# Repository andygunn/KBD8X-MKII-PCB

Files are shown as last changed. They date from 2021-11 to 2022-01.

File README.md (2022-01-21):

# KBD8X-MKII-PCB
This is the source for the PCB used in the [KBD8X MKII by KBDfans](https://kbdfans.com/collections/kbd8x-mkii/products/coming-soon-kbd8x-mkii-custom-mechanical-keyboard-kit) by [ai03](https://kb.ai03.me). There have been a number of modifications to this PCB:
- Changed the MX-only footprints to MX/Alps-compatible footprints.
- Modified the routing of traces to accomodate the new footprints.
- Changed the ATmega32U4 from the -MU variety to the -AU variety so it could be hand-soldered (due to component shortages)

This PCB should work with the same firmware files as the original PCB, as the MCU and matrix are the same.

Note that this PCB is offered as-is with NO WARRANTY. If you produce it, you may encounter problems.

Please verify the conditions of the [license](https://github.com/ai03-2725/KBD8X-MKII-PCB/blob/master/LICENSE) before using.

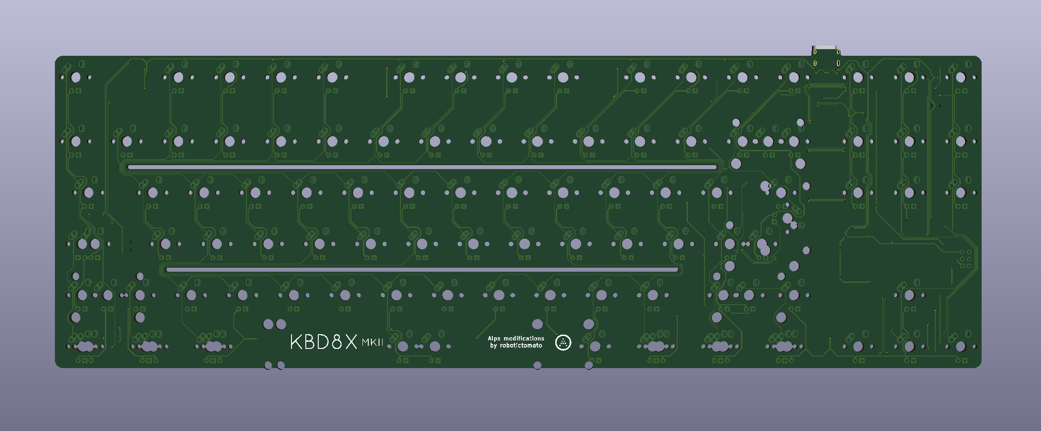
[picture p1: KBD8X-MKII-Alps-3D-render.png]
render


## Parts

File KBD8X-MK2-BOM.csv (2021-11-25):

Comment | Designator | Footprint | LCSC
1uF | C2 | locallib:C_0603 | C15849
22pF | C3,C4 | locallib:C_0603 | C1653
10uF | C5 | locallib:C_0603 | C19702
0.1uF | CRGB1,CRGB2,CRGB3,CRGB4,CRGB5,C6,CRGB6,C7,CRGB7,C8,CRGB8,CRGB9,CRGB10,CRGB11,CRGB12,CRGB13,CRGB14,CRGB15,CRGB16,CRGB17,CRGB18 | locallib:C_0603 | C2167300
SOD-323 | D1,D2,D3,D4,D5,D6,D7,D8,D9,D10,D11,D12,D13,D14,D17,D18,D19,D20,D21,D22,D23,D24,D25,D26,D27,D28,D29,D30,D31,D35,D36,D37,D38,D39,D40,D41,D42,D43,D44,D45,D46,D47,D48,D52,D53,D54,D55,D56,D57,D58,D59,D60,D61,D62,D63,D65,D66,D67,D68,D69,D70,D71,D72,D73,D74,D75,D76,D77,D78,D81,D82,D84,D85,D86,D87,D90,D91,D92,D93,D94,D95,D96,D97,D99,D100,D101,D108,D111,D112,D113 | locallib:D_SOD-123 | C81598
500mA | F1 | Fuse_Holders_and_Fuses:Fuse_SMD1206_Wave | C151162
DSS60601MZ4-13 | Q1 | TO_SOT_Packages_SMD:SOT-223-3_TabPin2 | C150451
22 | RC1,RC2 | locallib:R_0603 | C23345
10k | RC3 | locallib:R_0603 | C25804
1k | R1,R2,R3,RC4,R4,R5,R6,R7,R8,R9,R10,R11,R12,R13,R14,R16,R17,R18,R19,R20,R21,R22,R23,R24,R25,R26,R27,R28,R29,R30,R31,R32,R33,R35,R36,R37,R38,R39,R40,R41,R42,R43,R44,R45,R46,R47,R48,R52,R53,R54,R55,R56,R57,R58,R59,R60,R61,R62,R63,R65,R66,R67,R68,R69,R70,R71,R72,R73,R74,R75,R76,R77,R78,R81,R82,R84,R85,R86,R87,R90,R91,R95,R96,R97,R99,R100,R101,R108,R111,R112,R113 | locallib:R_0603 | C21190
1.5k | RC5 | locallib:R_0603 | C22843
5k1 | RC6,RC7 | locallib:R_0603 | C23186
WS2812B | RGB1,RGB2,RGB3,RGB4,RGB5,RGB6,RGB7,RGB8,RGB9,RGB10,RGB11,RGB12,RGB13,RGB14,RGB15,RGB16,RGB17,RGB18 | locallib:LED_WS2812B-PLCC4 | C2761795
SW_Push | SW1 | random-keyboard-parts:SKQG-1155865 | C116647
SW_SPDT | SW2,SW3 | Buttons_Switches_SMD:SW_SPDT_PCM12 | C221841
ATmega32U4-MU | U1 | locallib:QFN-44-1EP_7x7mm_Pitch0.5mm | C112161
PRTR5V0U2X | U2 | locallib:SOT143B | C12333
HRO-TYPE-C-31-M-12 | USB1 | Type-C:HRO-TYPE-C-31-M-12-Assembly | C165948
16MHz | Y1 | locallib:Crystal_SMD_3225-4pin_3.2x2.5mm | C255906

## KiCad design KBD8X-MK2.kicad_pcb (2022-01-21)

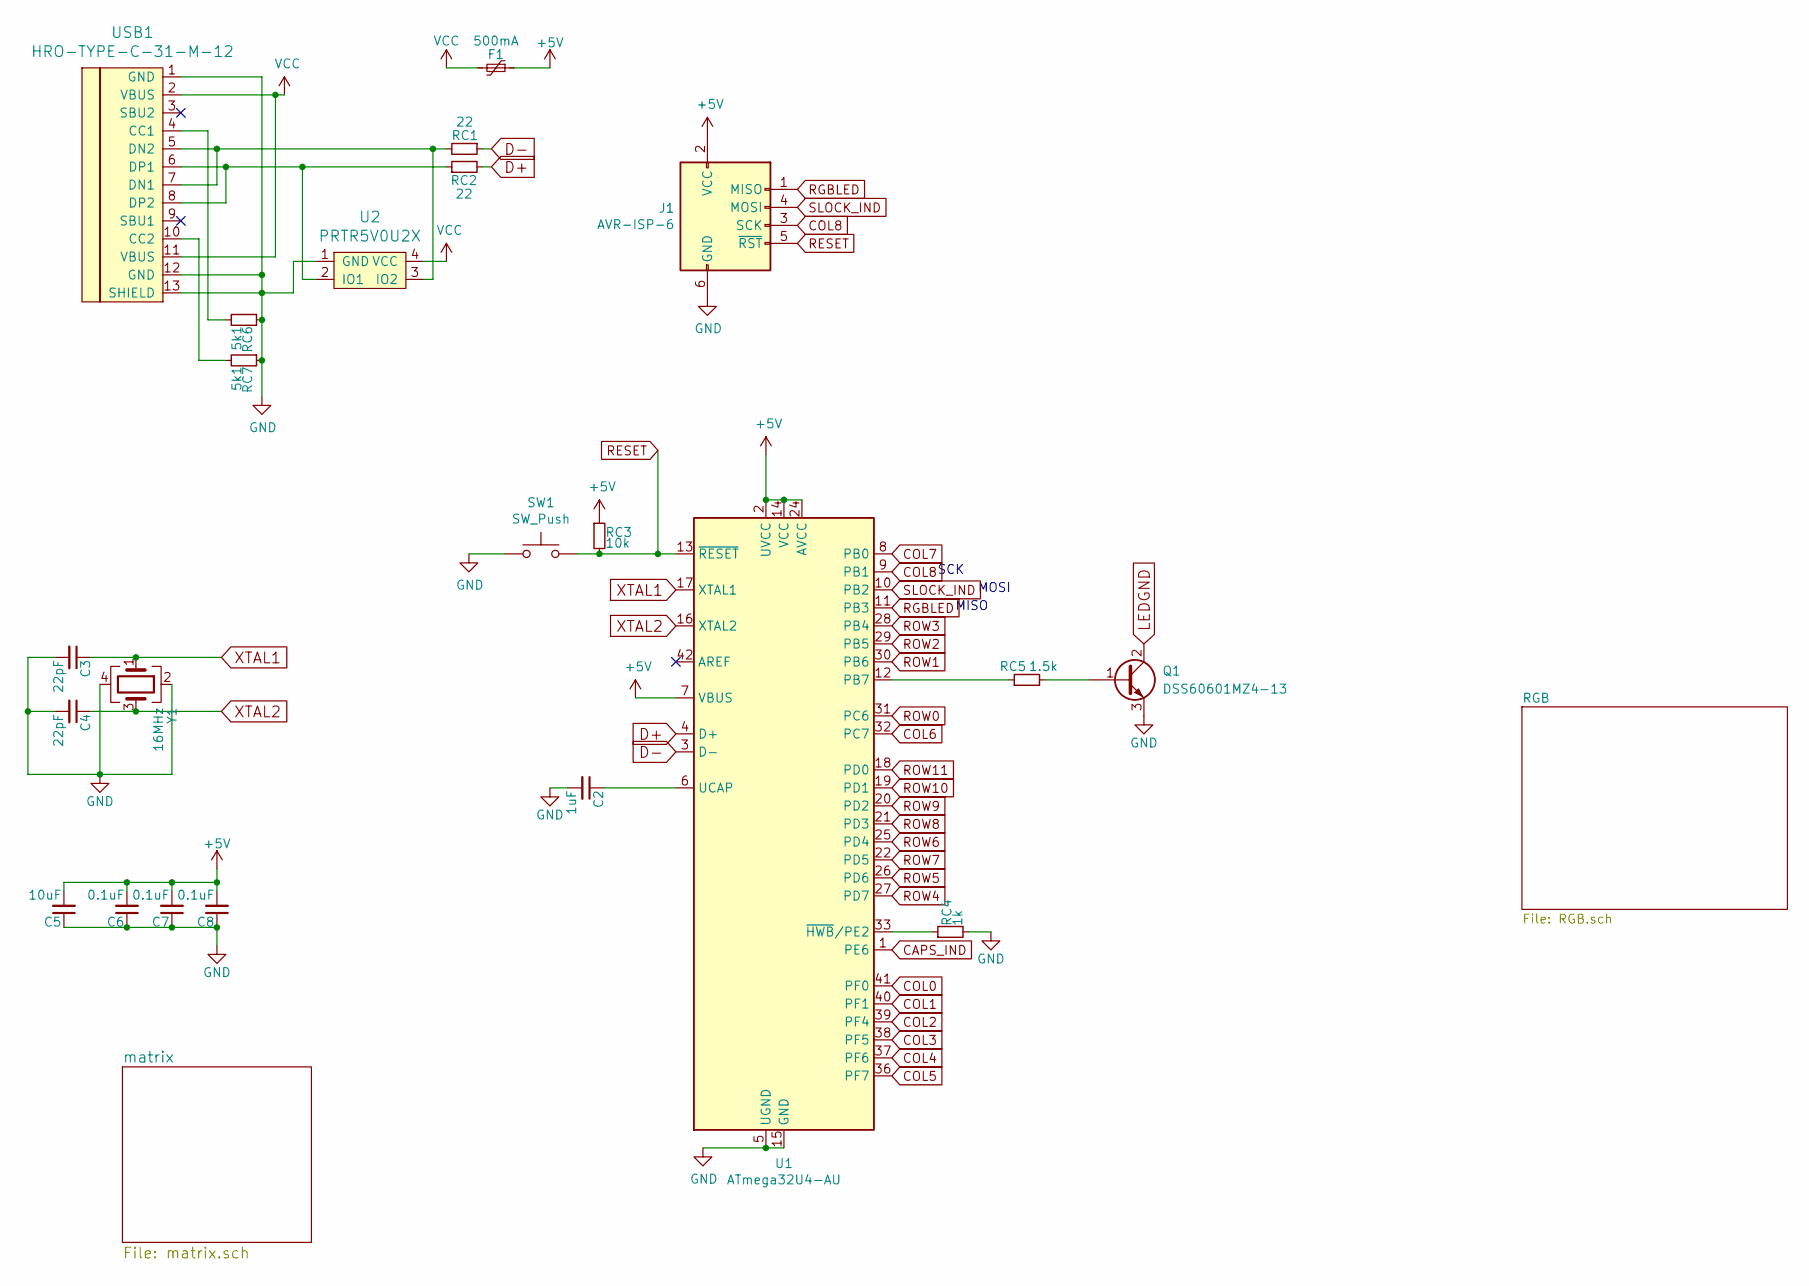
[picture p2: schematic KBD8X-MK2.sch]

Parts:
C2: 1uF; C_0603
C3, C4: 22pF; C_0603
C5: 10uF; C_0603
C6, C7, C8: 0.1uF; C_0603
F1: 500mA; Fuse_SMD1206_Wave
J1: AVR-ISP-6; Reset_Pretty-Mask
Q1: DSS60601MZ4-13; SOT-223-3_TabPin2
RC1, RC2: 22; R_0603
RC3: 10k; R_0603
RC4: 1k; R_0603
RC5: 1.5k; R_0603
RC6, RC7: 5k1; R_0603
SW1: SW_Push; SKQG-1155865
U1: ATmega32U4-AU; TQFP-44_10x10mm_P0.8mm
U2: PRTR5V0U2X; SOT143B
USB1: HRO-TYPE-C-31-M-12; HRO-TYPE-C-31-M-12-Assembly
Y1: 16MHz; Crystal_SMD_3225-4pin_3.2x2.5mm

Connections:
+5V: C5.2, C6.2, C7.2, C8.2, F1.1, J1.2 (VCC), RC3.1, U1.2 (UVCC), U1.7 (VBUS), U1.14 (VCC), U1.24 (AVCC), U1.34 (VCC), U1.44 (AVCC); also elsewhere on the board
CAPS_IND: U1.1 (PE6); also elsewhere on the board
COL0: U1.41 (PF0); also elsewhere on the board
COL1: U1.40 (PF1); also elsewhere on the board
COL2: U1.39 (PF4); also elsewhere on the board
COL3: U1.38 (PF5); also elsewhere on the board
COL4: U1.37 (PF6); also elsewhere on the board
COL5: U1.36 (PF7); also elsewhere on the board
COL6: U1.32 (PC7); also elsewhere on the board
COL7: U1.8 (PB0); also elsewhere on the board
COL8: J1.3 (SCK), U1.9 (PB1); also elsewhere on the board
D+: RC2.2, U1.4 (D+)
D-: RC1.1, U1.3 (D-)
GND: C2.2, C3.2, C4.2, C5.1, C6.1, C7.1, C8.1, J1.6 (GND), Q1.3 (E), RC4.2, RC6.1, RC7.1, SW1.1, U1.5 (UGND), U1.15 (GND), U1.23 (GND), U1.35 (GND), U1.43 (GND), U1.45 (GND), U2.1 (GND), USB1.1 (GND), USB1.12 (GND), USB1.13 (SHIELD), Y1.2, Y1.4; also elsewhere on the board
LEDGND: Q1.2 (C); also elsewhere on the board
unnamed: C2.1, U1.6 (UCAP)
unnamed: Q1.1 (B), RC5.2
unnamed: RC1.2, U2.3 (IO2), USB1.5 (DN2), USB1.7 (DN1)
unnamed: RC2.1, U2.2 (IO1), USB1.6 (DP1), USB1.8 (DP2)
unnamed: RC4.1, U1.33 (~HWB~/PE2)
unnamed: RC5.1, U1.12 (PB7)
unnamed: RC6.2, USB1.4 (CC1)
unnamed: RC7.2, USB1.10 (CC2)
RESET: J1.5 (~RST), RC3.2, SW1.2, U1.13 (~RESET)
RGBLED: J1.1 (MISO), U1.11 (PB3); also elsewhere on the board
ROW0: U1.31 (PC6); also elsewhere on the board
ROW1: U1.30 (PB6); also elsewhere on the board
ROW2: U1.29 (PB5); also elsewhere on the board
ROW3: U1.28 (PB4); also elsewhere on the board
ROW4: U1.27 (PD7); also elsewhere on the board
ROW5: U1.26 (PD6); also elsewhere on the board
ROW6: U1.25 (PD4); also elsewhere on the board
ROW7: U1.22 (PD5); also elsewhere on the board
ROW8: U1.21 (PD3); also elsewhere on the board
ROW9: U1.20 (PD2); also elsewhere on the board
ROW10: U1.19 (PD1); also elsewhere on the board
ROW11: U1.18 (PD0); also elsewhere on the board
SLOCK_IND: J1.4 (MOSI), U1.10 (PB2); also elsewhere on the board
VCC: F1.2, U2.4 (VCC), USB1.2 (VBUS), USB1.11 (VBUS)
XTAL1: C3.1, U1.17 (XTAL1), Y1.1
XTAL2: C4.1, U1.16 (XTAL2), Y1.3

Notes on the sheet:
MOSI
MISO
SCK

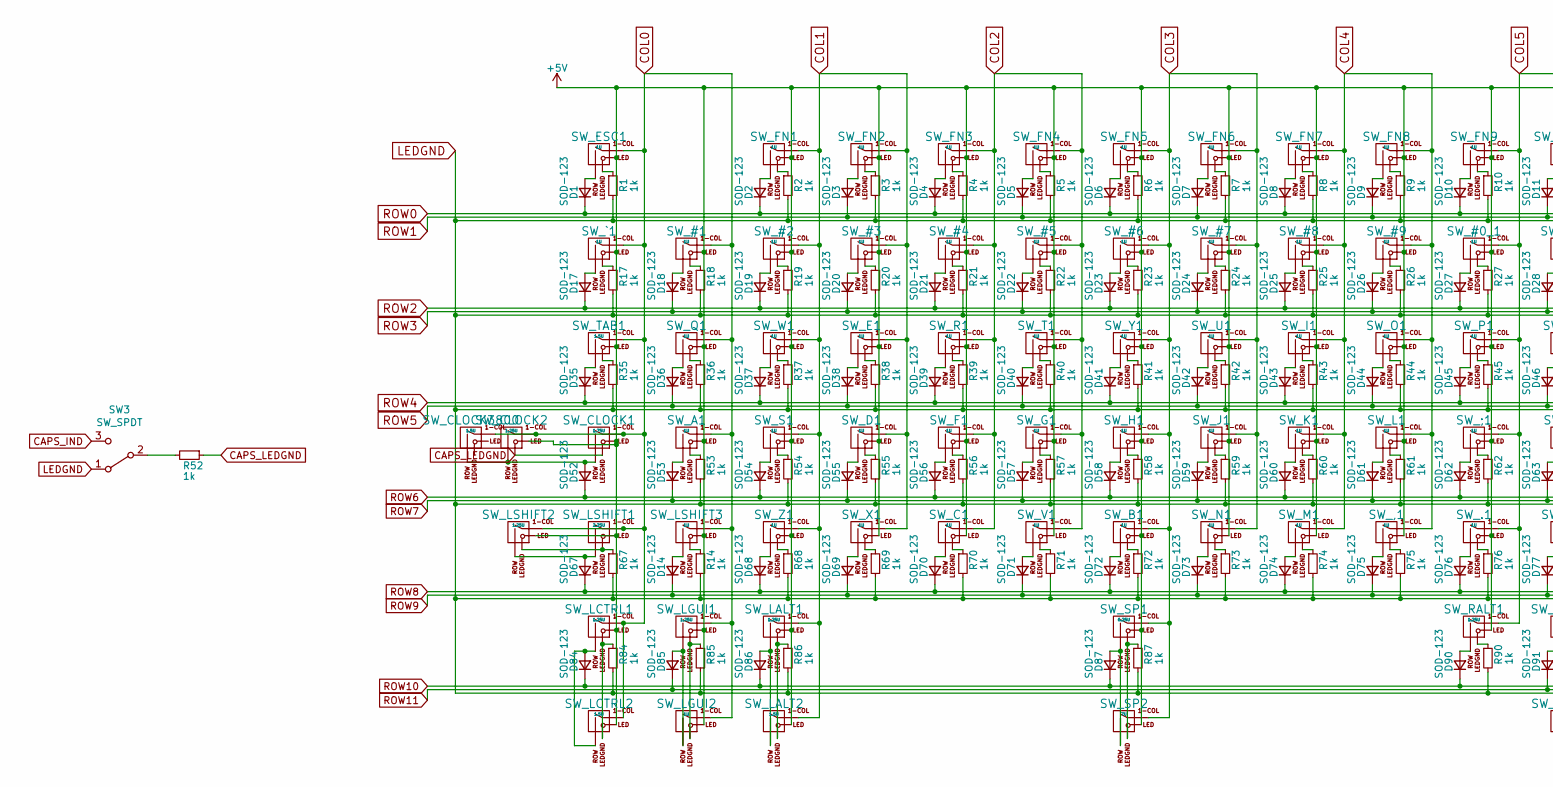
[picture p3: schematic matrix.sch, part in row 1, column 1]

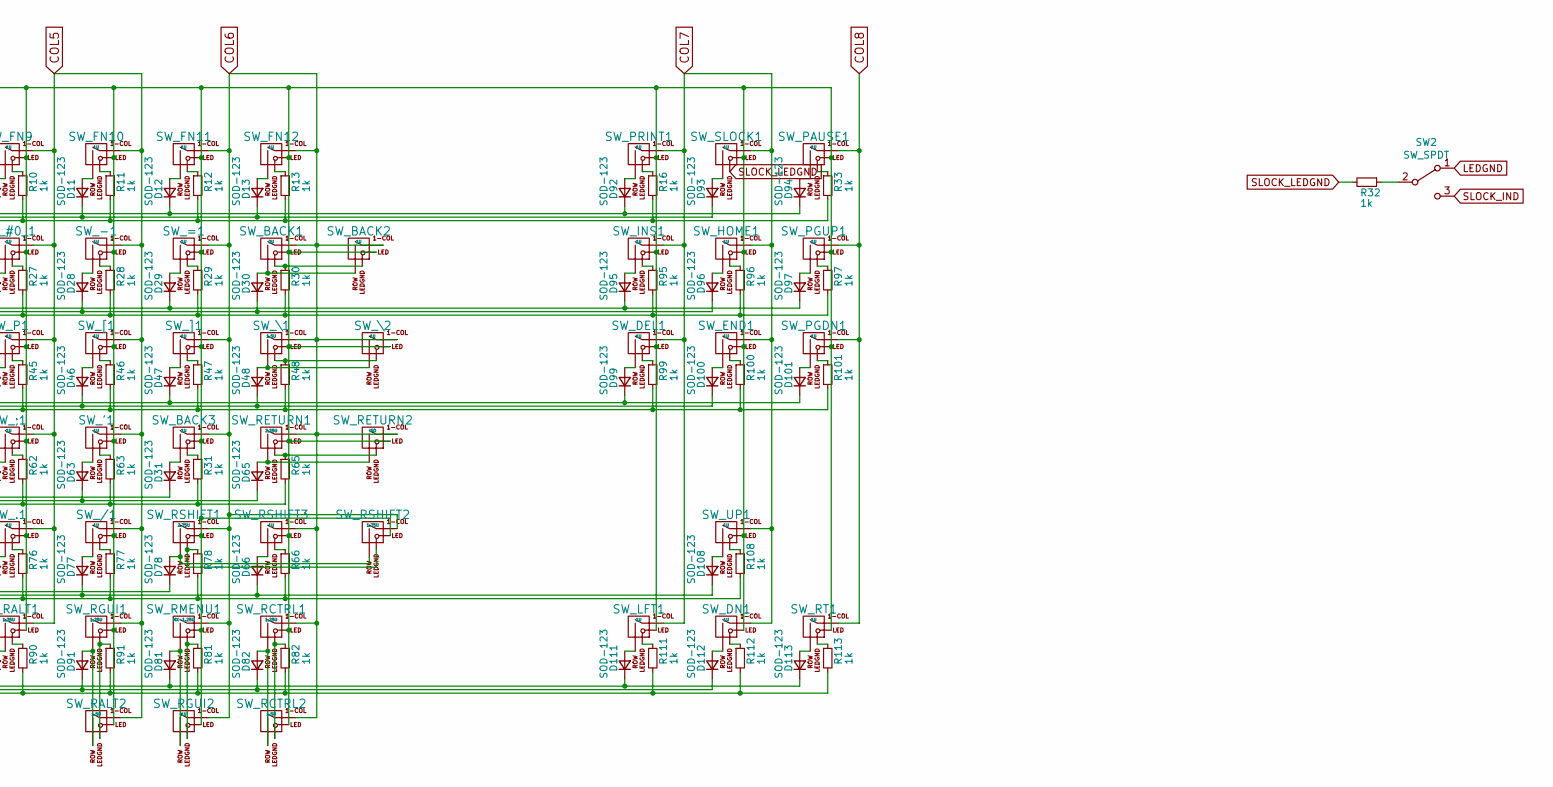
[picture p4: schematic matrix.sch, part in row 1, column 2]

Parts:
D1, D2, D3, D4, D5, D6, D7, D8, D9, D10, D11, D12, D13, D14, D17, D18, D19, D20, D21, D22, D23, D24, D25, D26, D27, D28, D29, D30, D31, D35, D36, D37, D38, D39, D40, D41, D42, D43, D44, D45, D46, D47, D48, D52, D53, D54, D55, D56, D57, D58, D59, D60, D61, D62, D63, D65, D66, D67, D68, D69, D70, D71, D72, D73, D74, D75, D76, D77, D78, D81, D82, D84, D85, D86, D87, D90, D91, D92, D93, D94, D95, D96, D97, D99, D100, D101, D108, D111, D112, D113: SOD-123; D_SOD-123
R1, R2, R3, R4, R5, R6, R7, R8, R9, R10, R11, R12, R13, R14, R16, R17, R18, R19, R20, R21, R22, R23, R24, R25, R26, R27, R28, R29, R30, R31, R32, R33, R35, R36, R37, R38, R39, R40, R41, R42, R43, R44, R45, R46, R47, R48, R52, R53, R54, R55, R56, R57, R58, R59, R60, R61, R62, R63, R65, R66, R67, R68, R69, R70, R71, R72, R73, R74, R75, R76, R77, R78, R81, R82, R84, R85, R86, R87, R90, R91, R95, R96, R97, R99, R100, R101, R108, R111, R112, R113: 1k; R_0603
SW2, SW3: SW_SPDT; SW_SPDT_PCM12
SW_#0_1, SW_#1, SW_#2, SW_#3, SW_#4, SW_#5, SW_#6, SW_#7, SW_#8, SW_#9: 1U; MX-1U
SW_'1: 1U; MX-1U
SW_,1: 1U; MX-1U
SW_-1: 1U; MX-1U
SW_.1: 1U; MX-1U
SW_/1: 1U; MX-1U
SW_;1: 1U; MX-1U
SW_=1: 1U; MX-1U
SW_A1: 1U; MX-1U
SW_B1: 1U; MX-1U
SW_BACK1: 2U; MX-2U
SW_BACK2, SW_BACK3: 1U; MX-1U
SW_C1: 1U; MX-1U
SW_CLOCK1: 1.75U; MX-1.75U
SW_CLOCK2: 1.25U; MX-1.25U-FLIPPED
SW_CLOCK3800: 1.5U; ALPS-1.5U
SW_D1: 1U; MX-1U
SW_DEL1: 1U; MX-1U
SW_DN1: 1U; MX-1U
SW_E1: 1U; MX-1U
SW_END1: 1U; MX-1U
SW_ESC1: 1U; MX-1U
SW_F1: 1U; MX-1U
SW_FN1, SW_FN2, SW_FN3, SW_FN4, SW_FN5, SW_FN6, SW_FN7, SW_FN8, SW_FN9, SW_FN10, SW_FN11, SW_FN12: 1U; MX-1U
SW_G1: 1U; MX-1U
SW_H1: 1U; MX-1U
SW_HOME1: 1U; MX-1U
SW_I1: 1U; MX-1U
SW_INS1: 1U; MX-1U
SW_J1: 1U; MX-1U
SW_K1: 1U; MX-1U
SW_L1: 1U; MX-1U
SW_LALT1: 1.25U; MX-1.25U
SW_LALT2: 1.5U; MX-1.5U-FLIPPED
SW_LCTRL1: 1.25U; MX-1.25U
SW_LCTRL2: 1.5U; MX-1.5U-FLIPPED
SW_LFT1: 1U; MX-1U
SW_LGUI1: 1.25U; MX-1.25U
SW_LGUI2: 1U; MX-1U-FLIPPED
SW_LSHIFT1: 2.25U; MX-2.25U
SW_LSHIFT2: 1.25U; MX-1.25U
SW_LSHIFT3: 1U; MX-1U
SW_M1: 1U; MX-1U
SW_N1: 1U; MX-1U
SW_O1: 1U; MX-1U
SW_P1: 1U; MX-1U
SW_PAUSE1: 1U; MX-1U
SW_PGDN1: 1U; MX-1U
SW_PGUP1: 1U; MX-1U
SW_PRINT1: 1U; MX-1U
SW_Q1: 1U; MX-1U
SW_R1: 1U; MX-1U
SW_RALT1: 1.25U; MX-1.25U
SW_RALT2: 1.5U; MX-1.5U
SW_RCTRL1: 1.25U; MX-1.25U-FLIPPED
SW_RCTRL2: 1.5U; MX-1.5U
SW_RETURN1: 2.25U; MX-2.25U
SW_RETURN2: ISO; MX-ISO-ReversedStabilizers
SW_RGUI1: 1.25U; MX-1.25U-FLIPPED
SW_RGUI2: 1U; MX-1U
SW_RMENU1: MX-1.25U; MX-1.25U-FLIPPED
SW_RSHIFT1: 2.75U; MX-2.75U
SW_RSHIFT2: 1.75U; MX-1.75U
SW_RSHIFT3: 1U; MX-1U
SW_RT1: 1U; MX-1U
SW_S1: 1U; MX-1U
SW_SLOCK1: 1U; MX-1U
SW_SP1: 6.25U; MX-6.25U-ReversedStabilizers
SW_SP2: 7U; MX-7U-ReversedStabilizers
SW_T1: 1U; MX-1U
SW_TAB1: 1.5U; MX-1.5U
SW_U1: 1U; MX-1U
SW_UP1: 1U; MX-1U
SW_V1: 1U; MX-1U
SW_W1: 1U; MX-1U
SW_X1: 1U; MX-1U
SW_Y1: 1U; MX-1U
SW_Z1: 1U; MX-1U
SW_[1: 1U; MX-1U
SW_\1: 1.5U; MX-1.5U
SW_\2: 1U; MX-1U
SW_]1: 1U; MX-1U
SW_`1: 1U; MX-1U

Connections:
+5V: SW_#0_1.3 (LED), SW_#1.3 (LED), SW_#2.3 (LED), SW_#3.3 (LED), SW_#4.3 (LED), SW_#5.3 (LED), SW_#6.3 (LED), SW_#7.3 (LED), SW_#8.3 (LED), SW_#9.3 (LED), SW_'1.3 (LED), SW_,1.3 (LED), SW_-1.3 (LED), SW_.1.3 (LED), SW_/1.3 (LED), SW_;1.3 (LED), SW_=1.3 (LED), SW_A1.3 (LED), SW_B1.3 (LED), SW_BACK1.3 (LED), SW_BACK2.3 (LED), SW_BACK3.3 (LED), SW_C1.3 (LED), SW_CLOCK1.3 (LED), SW_CLOCK2.3 (LED), SW_D1.3 (LED), SW_DEL1.3 (LED), SW_DN1.3 (LED), SW_E1.3 (LED), SW_END1.3 (LED), SW_ESC1.3 (LED), SW_F1.3 (LED), SW_FN1.3 (LED), SW_FN2.3 (LED), SW_FN3.3 (LED), SW_FN4.3 (LED), SW_FN5.3 (LED), SW_FN6.3 (LED), SW_FN7.3 (LED), SW_FN8.3 (LED), SW_FN9.3 (LED), SW_FN10.3 (LED), SW_FN11.3 (LED), SW_FN12.3 (LED), SW_G1.3 (LED), SW_H1.3 (LED), SW_HOME1.3 (LED), SW_I1.3 (LED), SW_INS1.3 (LED), SW_J1.3 (LED), SW_K1.3 (LED), SW_L1.3 (LED), SW_LALT1.3 (LED), SW_LALT2.3 (LED), SW_LCTRL1.3 (LED), SW_LCTRL2.3 (LED), SW_LFT1.3 (LED), SW_LGUI1.3 (LED), SW_LGUI2.3 (LED), SW_LSHIFT1.3 (LED), SW_LSHIFT2.3 (LED), SW_LSHIFT3.3 (LED), SW_M1.3 (LED), SW_N1.3 (LED), SW_O1.3 (LED), SW_P1.3 (LED), SW_PAUSE1.3 (LED), SW_PGDN1.3 (LED), SW_PGUP1.3 (LED), SW_PRINT1.3 (LED), SW_Q1.3 (LED), SW_R1.3 (LED), SW_RALT1.3 (LED), SW_RALT2.3 (LED), SW_RCTRL1.3 (LED), SW_RCTRL2.3 (LED), SW_RETURN1.3 (LED), SW_RETURN2.3 (LED), SW_RGUI1.3 (LED), SW_RGUI2.3 (LED), SW_RMENU1.3 (LED), SW_RSHIFT1.3 (LED), SW_RSHIFT2.3 (LED), SW_RSHIFT3.3 (LED), SW_RT1.3 (LED), SW_S1.3 (LED), SW_SLOCK1.3 (LED), SW_SP1.3 (LED), SW_SP2.3 (LED), SW_T1.3 (LED), SW_TAB1.3 (LED), SW_U1.3 (LED), SW_UP1.3 (LED), SW_V1.3 (LED), SW_W1.3 (LED), SW_X1.3 (LED), SW_Y1.3 (LED), SW_Z1.3 (LED), SW_[1.3 (LED), SW_\1.3 (LED), SW_\2.3 (LED), SW_]1.3 (LED), SW_`1.3 (LED); also elsewhere on the board
CAPS_IND: SW3.3 (C); also elsewhere on the board
CAPS_LEDGND: R52.1, SW_CLOCK1.4 (LEDGND), SW_CLOCK2.4 (LEDGND)
COL0: SW_#1.1 (COL), SW_A1.1 (COL), SW_CLOCK1.1 (COL), SW_CLOCK2.1 (COL), SW_CLOCK3800.1 (COL), SW_ESC1.1 (COL), SW_LCTRL1.1 (COL), SW_LCTRL2.1 (COL), SW_LGUI1.1 (COL), SW_LGUI2.1 (COL), SW_LSHIFT1.1 (COL), SW_LSHIFT2.1 (COL), SW_LSHIFT3.1 (COL), SW_Q1.1 (COL), SW_TAB1.1 (COL), SW_`1.1 (COL); also elsewhere on the board
COL1: SW_#2.1 (COL), SW_#3.1 (COL), SW_D1.1 (COL), SW_E1.1 (COL), SW_FN1.1 (COL), SW_FN2.1 (COL), SW_LALT1.1 (COL), SW_LALT2.1 (COL), SW_S1.1 (COL), SW_W1.1 (COL), SW_X1.1 (COL), SW_Z1.1 (COL); also elsewhere on the board
COL2: SW_#4.1 (COL), SW_#5.1 (COL), SW_C1.1 (COL), SW_F1.1 (COL), SW_FN3.1 (COL), SW_FN4.1 (COL), SW_G1.1 (COL), SW_R1.1 (COL), SW_T1.1 (COL), SW_V1.1 (COL); also elsewhere on the board
COL3: SW_#6.1 (COL), SW_#7.1 (COL), SW_B1.1 (COL), SW_FN5.1 (COL), SW_FN6.1 (COL), SW_H1.1 (COL), SW_J1.1 (COL), SW_N1.1 (COL), SW_SP1.1 (COL), SW_SP2.1 (COL), SW_U1.1 (COL), SW_Y1.1 (COL); also elsewhere on the board
COL4: SW_#8.1 (COL), SW_#9.1 (COL), SW_,1.1 (COL), SW_FN7.1 (COL), SW_FN8.1 (COL), SW_I1.1 (COL), SW_K1.1 (COL), SW_L1.1 (COL), SW_M1.1 (COL), SW_O1.1 (COL); also elsewhere on the board
COL5: SW_#0_1.1 (COL), SW_'1.1 (COL), SW_-1.1 (COL), SW_.1.1 (COL), SW_/1.1 (COL), SW_;1.1 (COL), SW_FN9.1 (COL), SW_FN10.1 (COL), SW_P1.1 (COL), SW_RALT1.1 (COL), SW_RALT2.1 (COL), SW_RGUI1.1 (COL), SW_[1.1 (COL); also elsewhere on the board
COL6: SW_=1.1 (COL), SW_BACK1.1 (COL), SW_BACK2.1 (COL), SW_BACK3.1 (COL), SW_FN11.1 (COL), SW_FN12.1 (COL), SW_RCTRL1.1 (COL), SW_RCTRL2.1 (COL), SW_RETURN1.1 (COL), SW_RETURN2.1 (COL), SW_RGUI2.1 (COL), SW_RMENU1.1 (COL), SW_RSHIFT1.1 (COL), SW_RSHIFT2.1 (COL), SW_RSHIFT3.1 (COL), SW_\1.1 (COL), SW_\2.1 (COL), SW_]1.1 (COL); also elsewhere on the board
COL7: SW_DEL1.1 (COL), SW_DN1.1 (COL), SW_END1.1 (COL), SW_HOME1.1 (COL), SW_INS1.1 (COL), SW_LFT1.1 (COL), SW_PRINT1.1 (COL), SW_SLOCK1.1 (COL), SW_UP1.1 (COL); also elsewhere on the board
COL8: SW_PAUSE1.1 (COL), SW_PGDN1.1 (COL), SW_PGUP1.1 (COL), SW_RT1.1 (COL); also elsewhere on the board
LEDGND: R1.2, R2.2, R3.2, R4.2, R5.2, R6.2, R7.2, R8.2, R9.2, R10.2, R11.2, R12.2, R13.2, R14.2, R16.2, R17.2, R18.2, R19.2, R20.2, R21.2, R22.2, R23.2, R24.2, R25.2, R26.2, R27.2, R28.2, R29.2, R30.2, R31.2, R33.2, R35.2, R36.2, R37.2, R38.2, R39.2, R40.2, R41.2, R42.2, R43.2, R44.2, R45.2, R46.2, R47.2, R48.2, R53.2, R54.2, R55.2, R56.2, R57.2, R58.2, R59.2, R60.2, R61.2, R62.2, R63.2, R65.2, R66.2, R67.2, R68.2, R69.2, R70.2, R71.2, R72.2, R73.2, R74.2, R75.2, R76.2, R77.2, R78.2, R81.2, R82.2, R84.2, R85.2, R86.2, R87.2, R90.2, R91.2, R95.2, R96.2, R97.2, R99.2, R100.2, R101.2, R108.2, R111.2, R112.2, R113.2, SW2.1 (A), SW3.1 (A); also elsewhere on the board
unnamed: D1.2 (A), SW_ESC1.2 (ROW)
unnamed: D2.2 (A), SW_FN1.2 (ROW)
unnamed: D3.2 (A), SW_FN2.2 (ROW)
unnamed: D4.2 (A), SW_FN3.2 (ROW)
unnamed: D5.2 (A), SW_FN4.2 (ROW)
unnamed: D6.2 (A), SW_FN5.2 (ROW)
unnamed: D7.2 (A), SW_FN6.2 (ROW)
unnamed: D8.2 (A), SW_FN7.2 (ROW)
unnamed: D9.2 (A), SW_FN8.2 (ROW)
unnamed: D10.2 (A), SW_FN9.2 (ROW)
unnamed: D11.2 (A), SW_FN10.2 (ROW)
unnamed: D12.2 (A), SW_FN11.2 (ROW)
unnamed: D13.2 (A), SW_FN12.2 (ROW)
unnamed: D14.2 (A), SW_LSHIFT3.2 (ROW)
unnamed: D17.2 (A), SW_`1.2 (ROW)
unnamed: D18.2 (A), SW_#1.2 (ROW)
unnamed: D19.2 (A), SW_#2.2 (ROW)
unnamed: D20.2 (A), SW_#3.2 (ROW)
unnamed: D21.2 (A), SW_#4.2 (ROW)
unnamed: D22.2 (A), SW_#5.2 (ROW)
unnamed: D23.2 (A), SW_#6.2 (ROW)
unnamed: D24.2 (A), SW_#7.2 (ROW)
unnamed: D25.2 (A), SW_#8.2 (ROW)
unnamed: D26.2 (A), SW_#9.2 (ROW)
unnamed: D27.2 (A), SW_#0_1.2 (ROW)
unnamed: D28.2 (A), SW_-1.2 (ROW)
unnamed: D29.2 (A), SW_=1.2 (ROW)
unnamed: D30.2 (A), SW_BACK1.2 (ROW), SW_BACK2.2 (ROW)
unnamed: D31.2 (A), SW_BACK3.2 (ROW)
unnamed: D35.2 (A), SW_TAB1.2 (ROW)
unnamed: D36.2 (A), SW_Q1.2 (ROW)
unnamed: D37.2 (A), SW_W1.2 (ROW)
unnamed: D38.2 (A), SW_E1.2 (ROW)
unnamed: D39.2 (A), SW_R1.2 (ROW)
unnamed: D40.2 (A), SW_T1.2 (ROW)
unnamed: D41.2 (A), SW_Y1.2 (ROW)
unnamed: D42.2 (A), SW_U1.2 (ROW)
unnamed: D43.2 (A), SW_I1.2 (ROW)
unnamed: D44.2 (A), SW_O1.2 (ROW)
unnamed: D45.2 (A), SW_P1.2 (ROW)
unnamed: D46.2 (A), SW_[1.2 (ROW)
unnamed: D47.2 (A), SW_]1.2 (ROW)
unnamed: D48.2 (A), SW_\1.2 (ROW), SW_\2.2 (ROW)
unnamed: D52.2 (A), SW_CLOCK1.2 (ROW), SW_CLOCK2.2 (ROW), SW_CLOCK3800.2 (ROW)
unnamed: D53.2 (A), SW_A1.2 (ROW)
unnamed: D54.2 (A), SW_S1.2 (ROW)
unnamed: D55.2 (A), SW_D1.2 (ROW)
unnamed: D56.2 (A), SW_F1.2 (ROW)
unnamed: D57.2 (A), SW_G1.2 (ROW)
unnamed: D58.2 (A), SW_H1.2 (ROW)
unnamed: D59.2 (A), SW_J1.2 (ROW)
unnamed: D60.2 (A), SW_K1.2 (ROW)
unnamed: D61.2 (A), SW_L1.2 (ROW)
unnamed: D62.2 (A), SW_;1.2 (ROW)
unnamed: D63.2 (A), SW_'1.2 (ROW)
unnamed: D65.2 (A), SW_RETURN1.2 (ROW), SW_RETURN2.2 (ROW)
unnamed: D66.2 (A), SW_RSHIFT3.2 (ROW)
unnamed: D67.2 (A), SW_LSHIFT1.2 (ROW), SW_LSHIFT2.2 (ROW)
unnamed: D68.2 (A), SW_Z1.2 (ROW)
unnamed: D69.2 (A), SW_X1.2 (ROW)
unnamed: D70.2 (A), SW_C1.2 (ROW)
unnamed: D71.2 (A), SW_V1.2 (ROW)
unnamed: D72.2 (A), SW_B1.2 (ROW)
unnamed: D73.2 (A), SW_N1.2 (ROW)
unnamed: D74.2 (A), SW_M1.2 (ROW)
unnamed: D75.2 (A), SW_,1.2 (ROW)
unnamed: D76.2 (A), SW_.1.2 (ROW)
unnamed: D77.2 (A), SW_/1.2 (ROW)
unnamed: D78.2 (A), SW_RSHIFT1.2 (ROW), SW_RSHIFT2.2 (ROW)
unnamed: D81.2 (A), SW_RGUI2.2 (ROW), SW_RMENU1.2 (ROW)
unnamed: D82.2 (A), SW_RCTRL1.2 (ROW), SW_RCTRL2.2 (ROW)
unnamed: D84.2 (A), SW_LCTRL1.2 (ROW), SW_LCTRL2.2 (ROW)
unnamed: D85.2 (A), SW_LGUI1.2 (ROW), SW_LGUI2.2 (ROW)
unnamed: D86.2 (A), SW_LALT1.2 (ROW), SW_LALT2.2 (ROW)
unnamed: D87.2 (A), SW_SP1.2 (ROW), SW_SP2.2 (ROW)
unnamed: D90.2 (A), SW_RALT1.2 (ROW)
unnamed: D91.2 (A), SW_RALT2.2 (ROW), SW_RGUI1.2 (ROW)
unnamed: D92.2 (A), SW_PRINT1.2 (ROW)
unnamed: D93.2 (A), SW_SLOCK1.2 (ROW)
unnamed: D94.2 (A), SW_PAUSE1.2 (ROW)
unnamed: D95.2 (A), SW_INS1.2 (ROW)
unnamed: D96.2 (A), SW_HOME1.2 (ROW)
unnamed: D97.2 (A), SW_PGUP1.2 (ROW)
unnamed: D99.2 (A), SW_DEL1.2 (ROW)
unnamed: D100.2 (A), SW_END1.2 (ROW)
unnamed: D101.2 (A), SW_PGDN1.2 (ROW)
unnamed: D108.2 (A), SW_UP1.2 (ROW)
unnamed: D111.2 (A), SW_LFT1.2 (ROW)
unnamed: D112.2 (A), SW_DN1.2 (ROW)
unnamed: D113.2 (A), SW_RT1.2 (ROW)
unnamed: R1.1, SW_ESC1.4 (LEDGND)
unnamed: R2.1, SW_FN1.4 (LEDGND)
unnamed: R3.1, SW_FN2.4 (LEDGND)
unnamed: R4.1, SW_FN3.4 (LEDGND)
unnamed: R5.1, SW_FN4.4 (LEDGND)
unnamed: R6.1, SW_FN5.4 (LEDGND)
unnamed: R7.1, SW_FN6.4 (LEDGND)
unnamed: R8.1, SW_FN7.4 (LEDGND)
unnamed: R9.1, SW_FN8.4 (LEDGND)
unnamed: R10.1, SW_FN9.4 (LEDGND)
unnamed: R11.1, SW_FN10.4 (LEDGND)
unnamed: R12.1, SW_FN11.4 (LEDGND)
unnamed: R13.1, SW_FN12.4 (LEDGND)
unnamed: R14.1, SW_LSHIFT3.4 (LEDGND)
unnamed: R16.1, SW_PRINT1.4 (LEDGND)
unnamed: R17.1, SW_`1.4 (LEDGND)
unnamed: R18.1, SW_#1.4 (LEDGND)
unnamed: R19.1, SW_#2.4 (LEDGND)
unnamed: R20.1, SW_#3.4 (LEDGND)
unnamed: R21.1, SW_#4.4 (LEDGND)
unnamed: R22.1, SW_#5.4 (LEDGND)
unnamed: R23.1, SW_#6.4 (LEDGND)
unnamed: R24.1, SW_#7.4 (LEDGND)
unnamed: R25.1, SW_#8.4 (LEDGND)
unnamed: R26.1, SW_#9.4 (LEDGND)
unnamed: R27.1, SW_#0_1.4 (LEDGND)
unnamed: R28.1, SW_-1.4 (LEDGND)
unnamed: R29.1, SW_=1.4 (LEDGND)
unnamed: R30.1, SW_BACK1.4 (LEDGND), SW_BACK2.4 (LEDGND)
unnamed: R31.1, SW_BACK3.4 (LEDGND)
unnamed: R32.1, SW2.2 (B)
unnamed: R33.1, SW_PAUSE1.4 (LEDGND)
unnamed: R35.1, SW_TAB1.4 (LEDGND)
unnamed: R36.1, SW_Q1.4 (LEDGND)
unnamed: R37.1, SW_W1.4 (LEDGND)
unnamed: R38.1, SW_E1.4 (LEDGND)
unnamed: R39.1, SW_R1.4 (LEDGND)
unnamed: R40.1, SW_T1.4 (LEDGND)
unnamed: R41.1, SW_Y1.4 (LEDGND)
unnamed: R42.1, SW_U1.4 (LEDGND)
unnamed: R43.1, SW_I1.4 (LEDGND)
unnamed: R44.1, SW_O1.4 (LEDGND)
unnamed: R45.1, SW_P1.4 (LEDGND)
unnamed: R46.1, SW_[1.4 (LEDGND)
unnamed: R47.1, SW_]1.4 (LEDGND)
unnamed: R48.1, SW_\1.4 (LEDGND), SW_\2.4 (LEDGND)
unnamed: R52.2, SW3.2 (B)
unnamed: R53.1, SW_A1.4 (LEDGND)
unnamed: R54.1, SW_S1.4 (LEDGND)
unnamed: R55.1, SW_D1.4 (LEDGND)
unnamed: R56.1, SW_F1.4 (LEDGND)
unnamed: R57.1, SW_G1.4 (LEDGND)
unnamed: R58.1, SW_H1.4 (LEDGND)
unnamed: R59.1, SW_J1.4 (LEDGND)
unnamed: R60.1, SW_K1.4 (LEDGND)
unnamed: R61.1, SW_L1.4 (LEDGND)
unnamed: R62.1, SW_;1.4 (LEDGND)
unnamed: R63.1, SW_'1.4 (LEDGND)
unnamed: R65.1, SW_RETURN1.4 (LEDGND), SW_RETURN2.4 (LEDGND)
unnamed: R66.1, SW_RSHIFT3.4 (LEDGND)
unnamed: R67.1, SW_LSHIFT1.4 (LEDGND), SW_LSHIFT2.4 (LEDGND)
unnamed: R68.1, SW_Z1.4 (LEDGND)
unnamed: R69.1, SW_X1.4 (LEDGND)
unnamed: R70.1, SW_C1.4 (LEDGND)
unnamed: R71.1, SW_V1.4 (LEDGND)
unnamed: R72.1, SW_B1.4 (LEDGND)
unnamed: R73.1, SW_N1.4 (LEDGND)
unnamed: R74.1, SW_M1.4 (LEDGND)
unnamed: R75.1, SW_,1.4 (LEDGND)
unnamed: R76.1, SW_.1.4 (LEDGND)
unnamed: R77.1, SW_/1.4 (LEDGND)
unnamed: R78.1, SW_RSHIFT1.4 (LEDGND), SW_RSHIFT2.4 (LEDGND)
unnamed: R81.1, SW_RGUI2.4 (LEDGND), SW_RMENU1.4 (LEDGND)
unnamed: R82.1, SW_RCTRL1.4 (LEDGND), SW_RCTRL2.4 (LEDGND)
unnamed: R84.1, SW_LCTRL1.4 (LEDGND), SW_LCTRL2.4 (LEDGND)
unnamed: R85.1, SW_LGUI1.4 (LEDGND), SW_LGUI2.4 (LEDGND)
unnamed: R86.1, SW_LALT1.4 (LEDGND), SW_LALT2.4 (LEDGND)
unnamed: R87.1, SW_SP1.4 (LEDGND), SW_SP2.4 (LEDGND)
unnamed: R90.1, SW_RALT1.4 (LEDGND)
unnamed: R91.1, SW_RALT2.4 (LEDGND), SW_RGUI1.4 (LEDGND)
unnamed: R95.1, SW_INS1.4 (LEDGND)
unnamed: R96.1, SW_HOME1.4 (LEDGND)
unnamed: R97.1, SW_PGUP1.4 (LEDGND)
unnamed: R99.1, SW_DEL1.4 (LEDGND)
unnamed: R100.1, SW_END1.4 (LEDGND)
unnamed: R101.1, SW_PGDN1.4 (LEDGND)
unnamed: R108.1, SW_UP1.4 (LEDGND)
unnamed: R111.1, SW_LFT1.4 (LEDGND)
unnamed: R112.1, SW_DN1.4 (LEDGND)
unnamed: R113.1, SW_RT1.4 (LEDGND)
ROW0: D1.1 (K), D2.1 (K), D4.1 (K), D6.1 (K), D8.1 (K), D10.1 (K), D12.1 (K), D92.1 (K), D94.1 (K); also elsewhere on the board
ROW1: D3.1 (K), D5.1 (K), D7.1 (K), D9.1 (K), D11.1 (K), D13.1 (K), D93.1 (K); also elsewhere on the board
ROW2: D17.1 (K), D19.1 (K), D21.1 (K), D23.1 (K), D25.1 (K), D27.1 (K), D29.1 (K), D95.1 (K), D97.1 (K); also elsewhere on the board
ROW3: D18.1 (K), D20.1 (K), D22.1 (K), D24.1 (K), D26.1 (K), D28.1 (K), D30.1 (K), D96.1 (K); also elsewhere on the board
ROW4: D35.1 (K), D37.1 (K), D39.1 (K), D41.1 (K), D43.1 (K), D45.1 (K), D47.1 (K), D99.1 (K), D101.1 (K); also elsewhere on the board
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

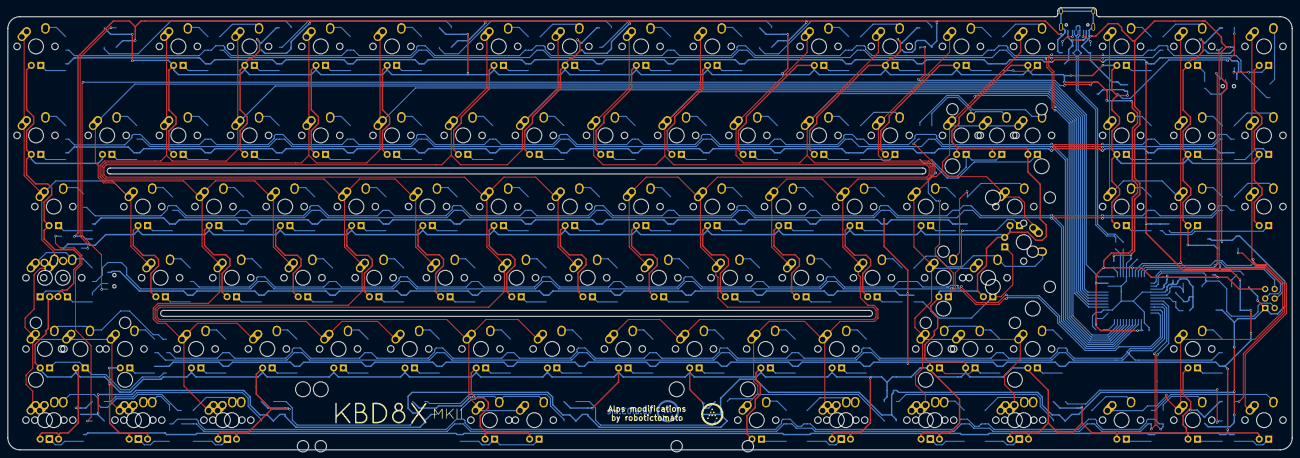
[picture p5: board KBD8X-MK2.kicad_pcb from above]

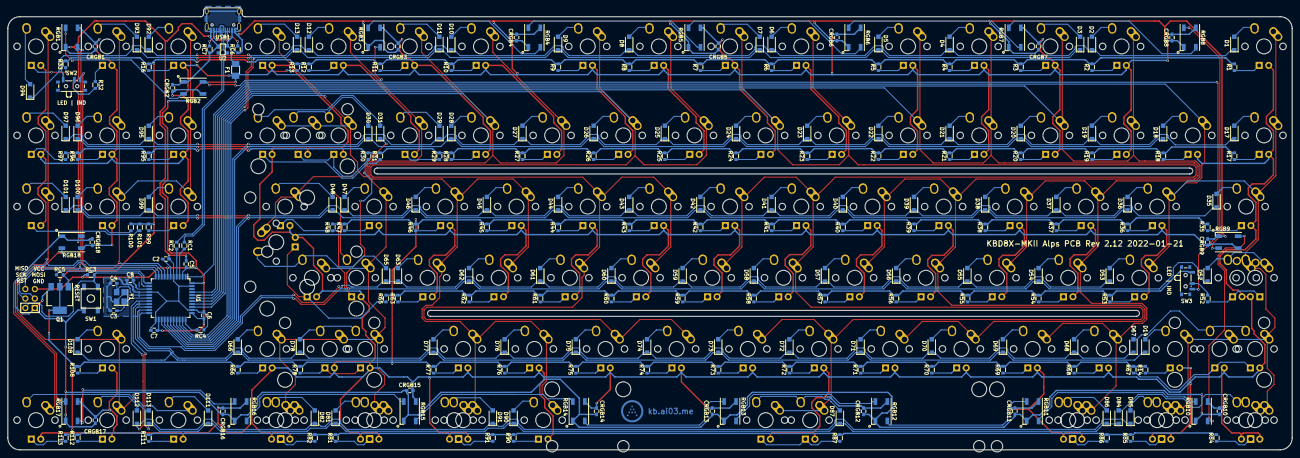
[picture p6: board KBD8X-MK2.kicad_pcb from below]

Board: 2 copper layers, 343.7 x 118.3 mm, 344 parts (240 on the bottom side), 240 nets.

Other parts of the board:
CRGB1, CRGB2, CRGB3, CRGB4, CRGB5, CRGB6, CRGB7, CRGB8, CRGB9, CRGB10, CRGB11, CRGB12, CRGB13, CRGB14, CRGB15, CRGB16, CRGB17, CRGB18: 0.1uF; C_0603
RGB1, RGB2, RGB3, RGB4, RGB5, RGB6, RGB7, RGB8, RGB9, RGB10, RGB11, RGB12, RGB13, RGB14, RGB15, RGB16, RGB17, RGB18: WS2812B; LED_WS2812B-PLCC4

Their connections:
+5V: CRGB1.1, CRGB2.1, CRGB3.1, CRGB4.1, CRGB5.1, CRGB6.1, CRGB7.1, CRGB8.1, CRGB9.1, CRGB10.1, CRGB11.1, CRGB12.1, CRGB13.1, CRGB14.1, CRGB15.1, CRGB16.1, CRGB17.1, CRGB18.1, RGB1.1, RGB2.1, RGB3.1, RGB4.1, RGB5.1, RGB6.1, RGB7.1, RGB8.1, RGB9.1, RGB10.1, RGB11.1, RGB12.1, RGB13.1, RGB14.1, RGB15.1, RGB16.1, RGB17.1, RGB18.1; also elsewhere on the board
GND: CRGB1.2, CRGB2.2, CRGB3.2, CRGB4.2, CRGB5.2, CRGB6.2, CRGB7.2, CRGB8.2, CRGB9.2, CRGB10.2, CRGB11.2, CRGB12.2, CRGB13.2, CRGB14.2, CRGB15.2, CRGB16.2, CRGB17.2, CRGB18.2, RGB1.3, RGB2.3, RGB3.3, RGB4.3, RGB5.3, RGB6.3, RGB7.3, RGB8.3, RGB9.3, RGB10.3, RGB11.3, RGB12.3, RGB13.3, RGB14.3, RGB15.3, RGB16.3, RGB17.3, RGB18.3; also elsewhere on the board
unnamed: RGB1.2, RGB2.4
unnamed: RGB2.2, RGB3.4
unnamed: RGB3.2, RGB4.4
unnamed: RGB4.2, RGB5.4
unnamed: RGB5.2, RGB6.4
unnamed: RGB6.2, RGB7.4
unnamed: RGB7.2, RGB8.4
unnamed: RGB8.2, RGB9.4
unnamed: RGB10.2, RGB11.4
unnamed: RGB9.2, RGB10.4
unnamed: RGB11.2, RGB12.4
unnamed: RGB12.2, RGB13.4
unnamed: RGB13.2, RGB14.4
unnamed: RGB14.2, RGB15.4
unnamed: RGB15.2, RGB16.4
unnamed: RGB16.2, RGB17.4
unnamed: RGB17.2, RGB18.4
RGBLED: RGB1.4; also elsewhere on the board

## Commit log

2021-11-23 Footprint updates top two rows
    Footprints have been updated on the top two rows of the PCB to add Alps switch compatibility.
    [KBD8X-MK2.kicad_pcb]
2021-11-24 Additional row footprint update
    Update of a row of footprints from MX only to Alps compatible.
    [KBD8X-MK2.kicad_pcb, matrix.sch]
2021-11-24 Additional row of footprint updates
    Enter row footprints updated to Alps compatible.
    [KBD8X-MK2.kicad_pcb, matrix.sch]
2021-11-25 Additional footprint updates
    [KBD8X-MK2.kicad_pcb, matrix.sch]
2021-11-25 Final footprint updates
    All rows have been updated to Alps compatible switch footprints.
    [KBD8X-MK2.kicad_pcb, matrix.sch]
2021-11-25 Gerber file changes
    Removal of the old Gerber file and creation of a new one. A new JPG file was also generated with the changes.
    [DXP_1921_1.csv.csv, DXP_1921_1.place.csv.csv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]
2021-11-25 BOM and POS file updates
    Working on updating the positioning and BOM files for use with JLCPCB.
    [KBD8X-MK2-BOM.csv, KBD8X-MK2.kicad_pcb, matrix.sch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]
2021-11-26 BOM updates
    Updated BOM for JLCPCB with parts changes based on availability. Positioning changes for negative X position on bottom.
    [KBD8X-MK2-BOM.csv, KBD8XMK2-BOM-old.xlsx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]
2021-12-17 Fix PCB footprint mistake
    There was a mistake with one of the footprints, which was not changed. All footprints are now Alps-compatible and the Gerber files have been updated.
    [KBD8X-MK2-BOM.csv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]
2022-01-21 Updated for 3800 style Capslock
    Added additional footprint for the 3800-style caps lock key. Gerbers updated as well.
    [KBD8X-MK2-B_Cu.gbl, KBD8X-MK2-B_Mask.gbs, KBD8X-MK2-B_SilkS.gbo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]
2022-01-21 Small silkscreen update
    [KBD8X-MK2.kicad_pcb]
